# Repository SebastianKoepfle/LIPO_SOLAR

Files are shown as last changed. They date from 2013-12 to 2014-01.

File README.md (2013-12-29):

LIPO_SOLAR
==========

Project LIPO charger for foldable solar modules
drawn in EAGLE 6.4.0

µC: PIC18F4520

with a LCD display for indication of charging performance, load status and output power
and a Voltmeter function up to 15V.

Intern LIPO 3000mAh 3,6V
On switch to load a external LIPO.

Output: USB(5V)

max Input Voltage 35V
max charging current 2A
max output current 2,5A

by FxSt

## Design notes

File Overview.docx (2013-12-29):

Laderegler mit LiPo Akku für faltbare Solarmodule

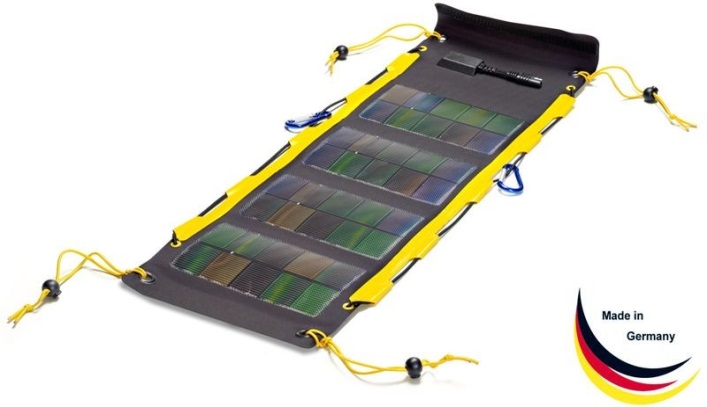
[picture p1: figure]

Voltmeter

µController

Leistungsüberwachung

PIC18f4520

Laderegler

LT3652

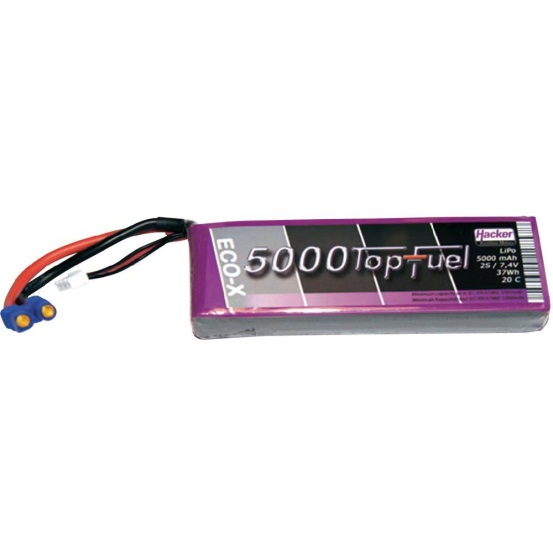
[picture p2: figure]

USB

3,6V to 5V converter

Anzeige(2 zeiliges LCD):

- Ladezustand
- Eingangsleistung
- Ausgangsleistung
- Voltmeter
- Temperatur

LCD

Taster

Schalter interner/externer Akku

USB

SOLAR IN

Externer Akku/ 3,6V Akkuspannung

Voltmeter

Eingang bis zu ca.40V

Ausgang 5V 2,5A

Max. Ladestrom Lipo 2A

Voltmeter bis 15V

µController:

- Messung der Eingangsleistung/Ausgangsleistung
- Begrenzung des Ausgangsstromes auf 2,5A
- Messung des Ladezustandes
- Fehlererkennung(Akkutemperatur, defekter Akku)
- Tiefentladeschutz
- µController und LCD Standby

Arbeitsaufteilung:

- Köpfle: µC Software
- Steinbacher: Schaltung + Print

Sebastian Köpfle Franz Steinbacher 4AHELS

Werkstätten Labor ProjektHTL Braunau2013/14

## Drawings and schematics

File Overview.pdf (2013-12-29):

# Laderegler mit LiPo Akku für faltbare Solarmodule

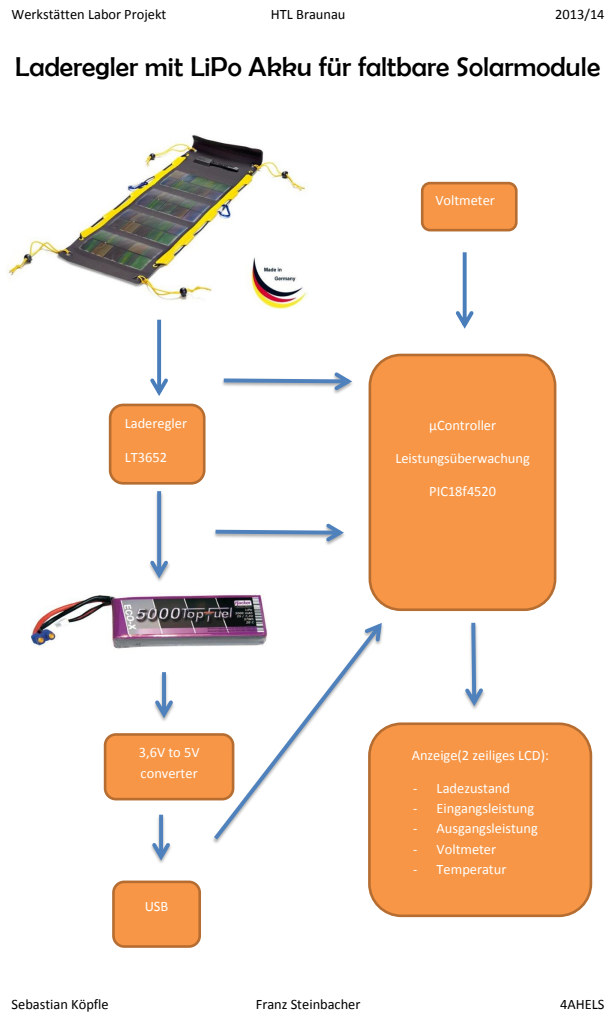
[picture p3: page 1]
Werkstätten Labor Projekt; HTL Braunau; Sebastian Köpfle; Franz Steinbacher; 4AHELS; Laderegler; µController; Leistungsüberwachung; PIC18f4520; - Ladezustand - Eingangsleistung - Ausgangsleistung - Voltmeter - Temperatur; USB; 3,6V to 5V converter; Voltmeter

Anzeige(2 zeiliges LCD):

Werkstätten Labor Projekt | HTL Braunau | 2013/14

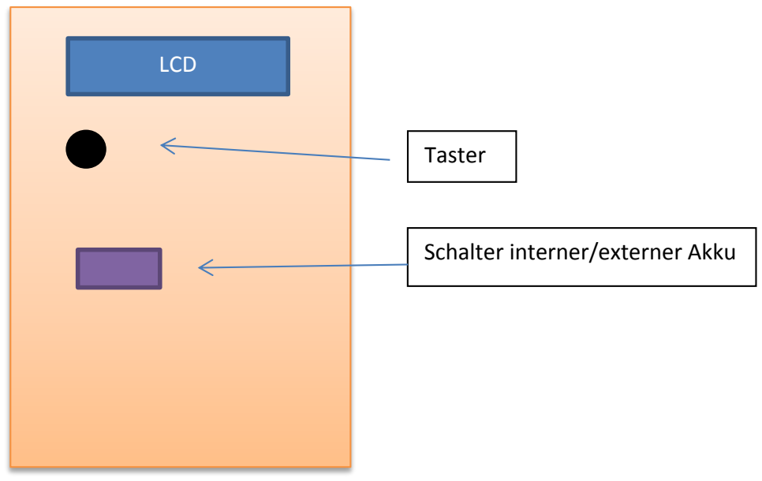
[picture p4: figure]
LCD; Taster; Schalter interner/externer Akku
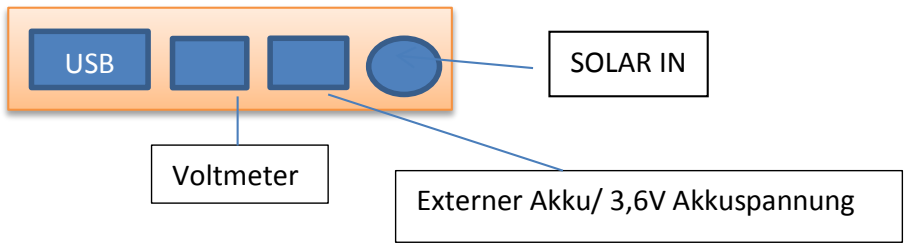
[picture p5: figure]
USB; SOLAR IN; Voltmeter; Externer Akku/ 3,6V Akkuspannung

Sebastian Köpfle | Franz Steinbacher | 4AHELS

Eingang bis zu ca.40V
Ausgang 5V 2,5A
Max. Ladestrom Lipo 2A
Voltmeter bis 15V

### µController:

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

### Arbeitsaufteilung:

- Köpfle: µC Software
- Steinbacher: Schaltung + Print

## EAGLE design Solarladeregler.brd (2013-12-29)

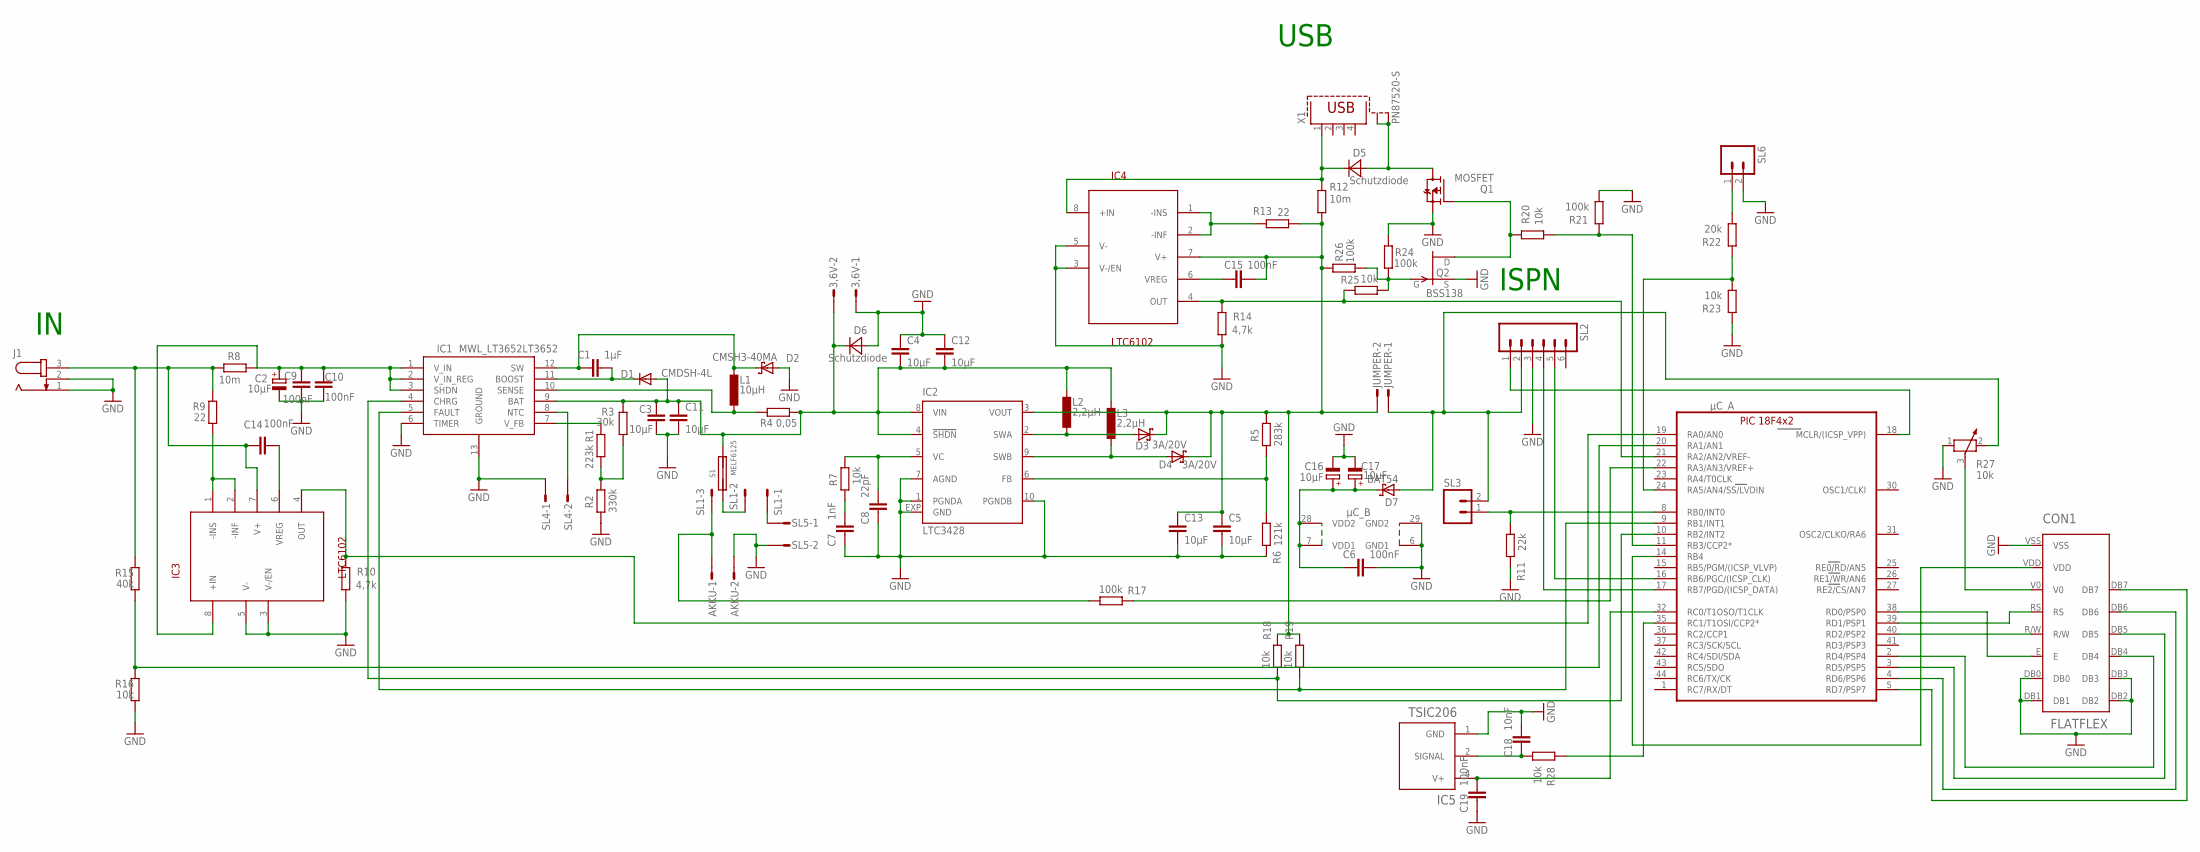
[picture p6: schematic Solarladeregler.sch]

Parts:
3,6V: M02S; 02P
AKKU: M02S; 02P
C1: 1µF; C0805
C2, C16, C17: 10µF; 153CLV-0505
C3, C4, C5, C11, C12, C13: 10µF; C0805
C6, C9, C10, C14, C15, C19: 100nF; C0805
C7: 1nF; C0805
C8: 22pF; C0805
C18: 10nF; C0805
CON1: FLATFLEX
D1: CMDSH-4L; SOD123
D2: CMSH3-40MA; SMB
D3, D4: 3A/20V; SMC
D5, D6: Schutzdiode; SMA
D7: BAT54; SOT23
IC1: MWL_LT3652LT3652; DFN12DD3X3
IC2: LTC3428; DFN10-3X3
IC3, IC4: LTC6102; MSOP8
IC5: TSIC206; SO08
J1: JACK-PLUG0; SPC4077
JUMPER: M02S; 02P
L1: 10µH; POWER-CHOKE_WE-TPC
L2, L3: 2,2µH; POWER-CHOKE_WE-TPC
Q1: MOSFET; TO252
Q2: BSS138; SOT23
R1: 223k; R0805
R2: 330k; R0805
R3: 30k; R0805
R4: 0,05; R0805
R5: 283k; R0805
R6: 121k; R0805
R7, R16, R18, R19, R20, R23, R25, R28: 10k; R0805
R8, R12: 10m; R2512
R9, R13: 22; R0805
R10, R14: 4,7k; R0805
R11: 22k; R0805
R15: 40k; R0805
R17, R21, R24, R26: 100k; R0805
R22: 20k; R0805
R27: 10k; PT-10
S1: MELF6125
SL1: M03S; 03P
SL2: M06; 06P
SL3, SL6: M02; 02P
SL4, SL5: M02S; 02P
X1: PN87520-S
µC: PIC18F4X2TQFP44; TQFP44

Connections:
GND: 3,6V.1, AKKU.2, C2.-, C3.2, C4.1, C5.2, C6.1, C7.2, C8.2, C9.2, C10.2, C11.2, C12.1, C13.2, C16.-, C17.-, C18.1, C19.2, CON1.DB0, CON1.DB1, CON1.DB2, CON1.DB3, CON1.VSS, D2.A, D6.A, IC1.6 (TIMER), IC1.13 (GROUND), IC2.1 (PGNDA), IC2.7 (AGND), IC2.10 (PGNDB), IC2.EXP (GND), IC3.3 (V-/EN), IC3.5 (V-), IC4.3 (V-/EN), IC4.5 (V-), IC5.1 (GND), J1.1, J1.2, Q1.2 (S), Q2.2 (S), R2.2, R6.2, R10.2, R11.2, R14.2, R16.2, R21.2, R23.1, R24.1, R27.1, SL2.3, SL4.1, SL5.2, SL6.2, µC.6 (GND1), µC.29 (GND2)
unnamed: CON1.E, µC.38 (RD0/PSP0)
unnamed: C1.1, D1.C, IC1.11 (BOOST)
unnamed: C2.+, C9.1, C10.1, IC1.1 (V_IN), IC1.2 (V_IN_REG), IC1.3 (SHDN), IC3.8 (+IN), R8.1
unnamed: IC1.10 (SENSE), L1.1, R4.2
unnamed: IC1.8 (NTC), SL4.2
unnamed: R1.2, R2.1, R3.1
unnamed: C1.2, D2.C, IC1.12 (SW), L1.2
unnamed: 3,6V.2, C3.1, C4.2, C11.1, C12.2, D1.A, D6.C, IC1.9 (BAT), IC2.4 (!SHDN), IC2.8 (VIN), L2.2, L3.2, R3.2, R4.1, S1.P$4
unnamed: C5.1, C13.1, C15.2, D3.C, D4.C, IC2.3 (VOUT), IC4.7 (V+), JUMPER.2, R5.1, R12.2, R13.2, R18.2, R19.2, R26.1
unnamed: D7.1 (A), JUMPER.1, R27.2, SL2.2, SL3.2
unnamed: D3.A, IC2.2 (SWA), L2.1
unnamed: C8.1, IC2.5 (VC), R7.1
unnamed: D4.A, IC2.9 (SWB), L3.1
unnamed: IC2.6 (FB), R5.2, R6.1
unnamed: C7.1, R7.2
unnamed: SL2.4, µC.17 (RB7/PGD/(ICSP_DATA))
unnamed: SL2.1, µC.18 (MCLR/(ICSP_VPP))
unnamed: SL2.5, µC.16 (RB6/PGC/(ICSP_CLK))
unnamed: IC3.1 (-INS), IC3.2 (-INF), R9.2
unnamed: C14.2, IC3.6 (VREG)
unnamed: IC3.4 (OUT), R10.1, µC.19 (RA0/AN0)
unnamed: D5.C, IC4.8 (+IN), R12.1, X1.1
unnamed: R11.1, SL3.1, µC.8 (RB0/INT0)
unnamed: IC4.1 (-INS), IC4.2 (-INF), R13.1
unnamed: C15.1, IC4.6 (VREG)
unnamed: IC4.4 (OUT), R14.1, R25.1, µC.21 (RA2/AN2/VREF-)
unnamed: R15.2, R16.1, µC.20 (RA1/AN1)
unnamed: IC1.7 (V_FB), R1.1
unnamed: R17.2, µC.22 (RA3/AN3/VREF+)
unnamed: AKKU.1, R17.1, SL1.3
unnamed: D5.A, Q1.3 (D), X1.S1, X1.S2
unnamed: SL1.1, SL5.1
unnamed: IC1.4 (CHRG), R18.1, µC.10 (RB2/INT2)
unnamed: IC1.5 (FAULT), R19.1, µC.9 (RB1/INT1)
unnamed: R20.2, R21.1, µC.11 (RB3/CCP2*)
unnamed: Q1.1 (G), Q2.1 (D), R20.1
unnamed: R22.2, SL6.1
unnamed: S1.P$3, SL1.2
unnamed: R22.1, R23.2, µC.24 (RA5/AN4/SS/LVDIN)
unnamed: Q2.3 (G), R24.2, R25.2, R26.2
unnamed: C6.2, C16.+, C17.+, D7.3 (C), µC.7 (VDD1), µC.28 (VDD2)
unnamed: C14.1, IC3.7 (V+), J1.3, R8.2, R9.1, R15.1
unnamed: CON1.RS, µC.39 (RD1/PSP1)
unnamed: CON1.R/W, µC.40 (RD2/PSP2)
unnamed: CON1.DB4, µC.2 (RD4/PSP4)
unnamed: CON1.DB5, µC.3 (RD5/PSP5)
unnamed: CON1.DB6, µC.4 (RD6/PSP6)
unnamed: CON1.DB7, µC.5 (RD7/PSP7)
unnamed: CON1.V0, R27.3
unnamed: R28.1, µC.35 (RC1/T1OSI/CCP2*)
unnamed: CON1.VDD, µC.14 (RB4)
unnamed: C19.1, IC5.4 (V+), µC.32 (RC0/T1OSO/T1CLK)
unnamed: C18.2, IC5.2 (SIGNAL), R28.2
OSC1/CLKI: µC.30 (OSC1/CLKI)
OSC2/CLKO/RA6: µC.31 (OSC2/CLKO/RA6)

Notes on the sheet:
USB
ISPN

Board: 2 copper layers, 78 parts (0 on the bottom side), 54 nets, no tracks yet.

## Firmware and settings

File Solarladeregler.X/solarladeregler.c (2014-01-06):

/* 
 * File:   solarladeregler.c
 * Author: Sebastian
 *
 * Created on 18. Oktober 2013, 14:13
 */
#include <pic18f4520.h>
#include <xc.h>
#include <plib.h>
#include "lcd.h"
#include <stdio.h>

#pragma config OSC = INTIO67
#pragma config LVP = OFF
#pragma config WDT = OFF
#pragma config MCLRE = ON
#pragma config XINST = OFF

/*
 *
 */

#define T0RELOAD 63536

#define TASTER1         PORTBbits.RB0
#define TRIS_TASTER1    TRISBbits.TRISB0

//unsigned char taster=0;
unsigned int zustand = 1;

void Init(void);

void main(void)
{
    int result;
    char strTemp[21];
    Init();

    LCD_string_xy(1,1,"Hallo");
    LCD_Cursor_OFF();

   // OpenADC( ADC_FOSC_64 & ADC_RIGHT_JUST & ADC_12_TAD, ADC_CH0 & ADC_CH1 & ADC_INT_OFF & ADC_REF_VDD_VSS,13);
    //SetChanADC( ADC_CH0 );

    while(1)
    {
        if (TASTER1 == 1)
        {
            zustand ++;
            if(zustand > 3)
            {
                zustand = 1;
            }

            switch(zustand)
            {
                case 1:
                    /*SetChanADC( ADC_CH0 );
                    ConvertADC(); // Start conversion
                    while( BusyADC() ); // Wait for completion
                    result = ReadADC(); // Read result

                    sprintf(strTemp,"ADC0=%4i",result);
                    LCD_string_xy(1,1,strTemp);*/
                    LCD_string_xy(1,2,"Ladestrom:");
                    LCD_Cursor_ON();                    
                    break;

                case 2:
                    LCD_string_xy(1,2,"Ausgangsstrom");
                    LCD_Cursor_ON();
                    break;

                case 3:
                    LCD_string_xy(1,2,"Ladezustand");
                    LCD_Cursor_ON();
                    break;
            }
     
        }
    }
}

void Init(void)
{
    OSCCON = 0x70;
    ADCON1= 0x0f;

    TRIS_TASTER1=1;

    LCD_Init();
    /*
    OpenTimer0(TIMER_INT_ON & T0_SOURCE_INT & T0_16BIT & T0_PS_1_1);
    WriteTimer0(T0RELOAD);
    GIE=1;*/
}
/*
void interrupt HIGH_ISR(void)
{
    if (TMR0IF == 1)
    {
        static unsigned int ms=0;
        static unsigned char gedr1=0;

        TMR0IF=0;
        WriteTimer0(T0RELOAD);

        ms++;
        if (ms >= 1000)
        {
            ms=0;
        }

        if ((ms % 100) == 0)
        {
            if(TASTER1 == 1 && gedr1 == 0)
            {
                gedr1=1;
                taster=1;
            }
            else if(TASTER1 == 0 && gedr1 == 1)
            {
                gedr1=0;
            }
        }
    }
}*/

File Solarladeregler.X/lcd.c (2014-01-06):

#include <xc.h>
#include <delays.h>
#include "lcd.h"


#define _LCDPORTD

#ifdef _LCDPORTD
#define E		PORTDbits.RD0
#define T_E		TRISDbits.TRISD0
#define RS		PORTDbits.RD1
#define T_RS		TRISDbits.TRISD1
#define RW		PORTDbits.RD2
#define T_RW		TRISDbits.TRISD2

#define DATA_P  	PORTD
#define TRIS_DATA_P	TRISD
#endif

#ifdef _LCDPORTC
#define E		PORTCbits.RC0
#define T_E		TRISCbits.TRISC0
#define RS		PORTCbits.RC1
#define T_RS		TRISCbits.TRISC1
#define RW		PORTCbits.RC2
#define T_RW		TRISCbits.TRISC2

#define DATA_P  	PORTC
#define TRIS_DATA_P	TRISC
#endif



//*****************************************************************************
//*****************************************************************************
void Delay_ms(int ms)
{
	 // Cycles = (1ms * Fosc) / 4 = (1ms * 8MHz) / 4 = 2000
	while(ms--)
		Delay1KTCYx(2);

}

//*****************************************************************************
//*****************************************************************************
unsigned char DisplayRead(char reg)
{
	unsigned char wert;

	TRIS_DATA_P |= 0xf0;

	RW=1;
        RS=reg;

	wert=0;

	E=1;
	E=1;
	E=1;
	wert=DATA_P & 0xf0;
	E=0;
	E=0;

	E=1;
	E=1;
	E=1;
	wert |= (DATA_P >> 4) & 0x0f;
	E=0;
	E=0;

	return wert;
}

//*****************************************************************************
//*****************************************************************************
void DisplayWrite(char reg, unsigned char d)
{
	TRIS_DATA_P &= 0x0f;
	DATA_P &= 0x0f;

	RW=0;
        RS=reg;

	E=1;
	E=1;
	DATA_P |= d & 0xf0;
	E=1;
	E=0;

	DATA_P &= 0x0f;
	Delay1TCY();

	E=1;
	E=1;
	DATA_P |= (d << 4) & 0xf0;
	E=1;
	E=0;

	Delay100TCYx(200);
}

//*****************************************************************************
//*****************************************************************************
void busy_lcd(void)
{
	unsigned char busy;

	do
	{
		busy=DisplayRead(0) & 0x80;
	} while(busy);
}

//*****************************************************************************
//*****************************************************************************
void LCD_Init(void)
{
	Delay_ms(15);

	DATA_P&= 0x0F;
	TRIS_DATA_P |= 0xf8; // Portbit 3 auf Eingang, da nicht benützt

	T_RW=0;
	T_RS=0;
	T_E=0;

	RW=0;
	RS=0;
	E=0;

	DisplayWrite(0,0x30);
	Delay_ms(5);

	DisplayWrite(0,0x30);
	Delay_ms(1);

	DisplayWrite(0,0x30);
	Delay_ms(1);

	DisplayWrite(0,0x20);
	Delay_ms(1);

	//Functionset, 4-Bit-Modus, 5*7 Punkte
	//Delay_ms(1);
	DisplayWrite(0,0x28);
	busy_lcd();

	// Display on/off
	DisplayWrite(0,0x0c);
	busy_lcd();

	// Display clear
	DisplayWrite(0,0x1);
	busy_lcd();

	// Set entry mode
	DisplayWrite(0,0x6);
	busy_lcd();
}

//*****************************************************************************
// links oben: x=1, y=1
//*****************************************************************************
void LCD_gotoxy(unsigned char x, unsigned char y)
{
	unsigned char adresse;

	switch(y)
	{
		case 1:
			adresse=0x00;
			break;
		case 2:
			adresse=0x40;
			break;
		case 3:
			adresse=0x14;
			break;
		case 4:
			adresse=0x54;
			break;
	}

	adresse += x-1;
	adresse |= 0x80;
	busy_lcd();
	DisplayWrite(0,adresse);
}

//*****************************************************************************
//*****************************************************************************
void LCD_string(char *text)
{
	while (*text != '\0')
	{
 		DisplayWrite(1,*text);
		text++;
	}
}

//*****************************************************************************
//*****************************************************************************
void LCD_string_xy(unsigned char x, unsigned char y,char *text)
{
	LCD_gotoxy(x,y);

	LCD_string(text);
}

//*****************************************************************************
//*****************************************************************************
void LCD_putc(unsigned char c)
{
	DisplayWrite(1,c);
	busy_lcd();
}

//*****************************************************************************
//*****************************************************************************
void LCD_Cursor_ON(void)
{
	DisplayWrite(0,0x0F);
}

//*****************************************************************************
//*****************************************************************************
void LCD_Cursor_OFF(void)
{
	DisplayWrite(0,0x0C);
}

//*****************************************************************************
//*****************************************************************************
void LCD_clear(void)
{
	DisplayWrite(0,0x01);
}

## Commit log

2013-12-29 Lipo Solar Projekt
    [LCD_klein.brd, Solarladeregler.brd, Solarladeregler.sch]
2013-12-29 all files
    [LCD_klein.brd, Solarladeregler.brd, Solarladeregler.sch]
2013-12-29 TSIC 206
    resistor +capacitor
    [Solarladeregler.brd, Solarladeregler.sch]
